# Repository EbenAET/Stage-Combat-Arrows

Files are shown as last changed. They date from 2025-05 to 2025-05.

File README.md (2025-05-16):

# Stage-Combat-Arrows
## A teaching tool for stage combat. These 3d printed arrows are large and easy to see. They point in the direction of the blade edge to help those training in stage combat to get used to blade orientation.

### Background: 
Professor Zev Steinrock at UIUC came to me requesting a simple solution to a visual tool he's incorporated when teaching his students the basics of stage combat with blades. Prof. Steinrock used hand cut cardboard arrows that would be skewered on the blades so the arrows would point towards the blade edge. Because of the time and material waste inherent in the creation of the cardboard arrows, he asked if I could come up with a simpler solution. Through basic iteration, I modeled a 3d printed arrow that contains a small rectangular window in the center and a screwdown clamp to keep a gripping medium in place. For the gripping medium, I've been using small rectangular cuts of neoprene yoga mats, though I am also trying out high friction rubber, and of course regular cardboard could be used as well. When the gripping medium wears out, it is easy to replace with another small rectangular piece. When using the neoprene and rubber, I recommend pre-punching screw holes to keep the material from jamming in the threads of the nuts.

### Included files:
- README | [README.md](https://github.com/EbenAET/Stage-Combat-Arrows/blob/b53a6de669d511d3e0b45057282f3c255a9eaaa4/README.md)
- Full drawings of model and assembly | [Combat Arrow v2.pdf](https://github.com/EbenAET/Stage-Combat-Arrows/blob/b33ad56709a9fc461572b4b7754411686f48d95c/Combat%20Arrow%20v2.pdf)
- Fusion360 Model | [Combat Arrow Assembly v9.f3z](https://github.com/EbenAET/Stage-Combat-Arrows/blob/0b1ade3ec6ca6f517fa18b048789da9054919ed2/3d-model/Combat%20Arrow%20Assembly%20v9.f3z)
- 3d Models for printing | [Arrow Body.3mf](https://github.com/EbenAET/Stage-Combat-Arrows/blob/0b1ade3ec6ca6f517fa18b048789da9054919ed2/3d-model/Arrow%20Body.3mf) and [Clamp.3mf](3d-model/Clamp.3mf)
- Prototype pictures | [Prototype image directory](images)
- Creative Commons License | [CC-A4](https://github.com/EbenAET/Stage-Combat-Arrows/blob/b53a6de669d511d3e0b45057282f3c255a9eaaa4/license)

### Materials needed (per unit made):
- 3x 6-32 Hex Nuts | [McMaster Carr Item 90480A007](https://www.mcmaster.com/90480A007/)
- 3x 6-32x1/4 Low Head SOC Cap Machine Screws | [McMaster Carr Item 93615A210](https://www.mcmaster.com/93615A210/)
- Super Glue
- Printer filament (I used PLA-CR)
- Finishing enamel (I used clear nail polish)
- Spray paint (if desired)
- Clear polycrylic (if paint is used)
- Gripping medium (I used neoprene rubber)

### 3d Printing Settings (PLA)
- Layer height - 0.08
- Ironing - All top surfaces
- Support - on (to help support hex sockets)

### Assembly
1. Print out both .3mf files
2. Glue 6-32 nuts into hex sockets - **be sure not to get glue in threads**
3. When glue is cured, apply enamel coat to 3d printed pieces
4. When enamel is cured, spray paint two even layers on all visable faces (if desired) | **I recommend setting screws into nuts for painting to keep paint from getting in the threads**
5. When paint is cured, lightly brush on one coat of clear polycrylic (if painted)
6. Cut a small rectangle of your gripping medium sized to fit in the arrow window frame
7. (Optional) pre-punch holes to make it easier to screw in machine screws
8. Compress gripping medium between arrow and clamp, install the 3 machine screws
9. Cut a small vertical slice in the center of the medium, smaller than the blade it will be used on
10. Skewer arrow on blade, pointing towards edge

### Alternate Assembly Notes
- Depending on thickness and grippyness of gripping medium, users may have to cut two small rectangles (slightly larger than half the width of the clamping size) and overlap in center.
- It is possible you may have to size up the machine screws if thickness of gripping medium is greater than what was used in the prototypes.

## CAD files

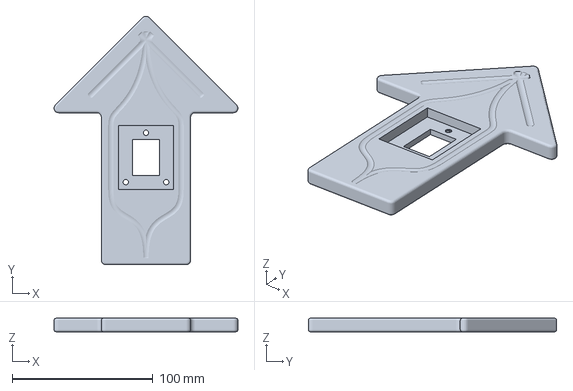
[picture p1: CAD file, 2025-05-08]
3d-model/Arrow Body.3mf
130.7 x 176.5 x 9.63 mm

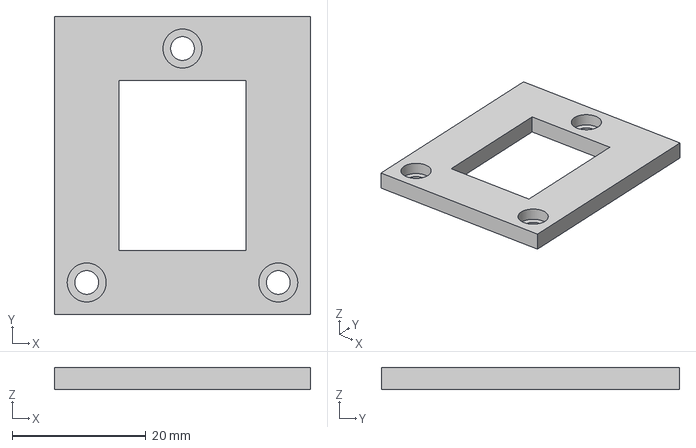
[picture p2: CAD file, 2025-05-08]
3d-model/Clamp.3mf
38.4 x 44.7 x 3.35 mm

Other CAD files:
3d-model/Combat Arrow Assembly v9.f3z

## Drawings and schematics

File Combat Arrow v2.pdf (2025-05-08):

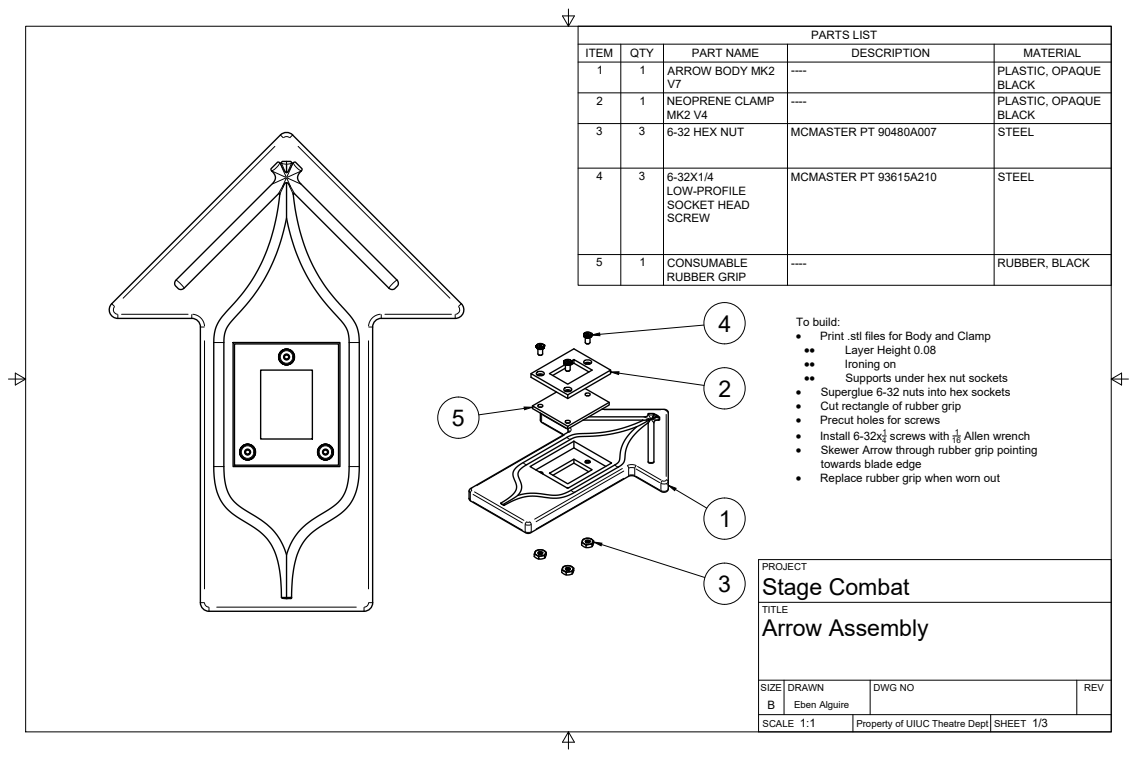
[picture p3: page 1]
Stage Combat; Arrow Assembly; PARTS LIST; To build:; Layer Height 0.08; Ironing on; Supports under hex nut sockets; screws with 1; Allen wrench

ITEM | QTY | PART NAME | DESCRIPTION | MATERIAL
1 | 1 | ARROW BODY MK2 V7 | ---- | PLASTIC, OPAQUE BLACK

2 | 1 | NEOPRENE CLAMP MK2 V4 | ---- | PLASTIC, OPAQUE BLACK

3 | 3 | 6-32 HEX NUT | MCMASTER PT 90480A007 | STEEL

4 | 3 | 6-32X1/4 LOW-PROFILE SOCKET HEAD SCREW | MCMASTER PT 93615A210 | STEEL

5 | 1 | CONSUMABLE RUBBER GRIP | ---- | RUBBER, BLACK

· Print .stl files for Body and Clamp
· Superglue 6-32 nuts into hex sockets
· Cut rectangle of rubber grip
· Precut holes for screws
· Install 6-32x1
· Skewer Arrow through rubber grip pointing
towards blade edge
· Replace rubber grip when worn out

SIZE B | DRAWN Eben Alguire | DWG NO | REV

1:1 SCALE | Property of UIUC Theatre Dept | 1/3 SHEET

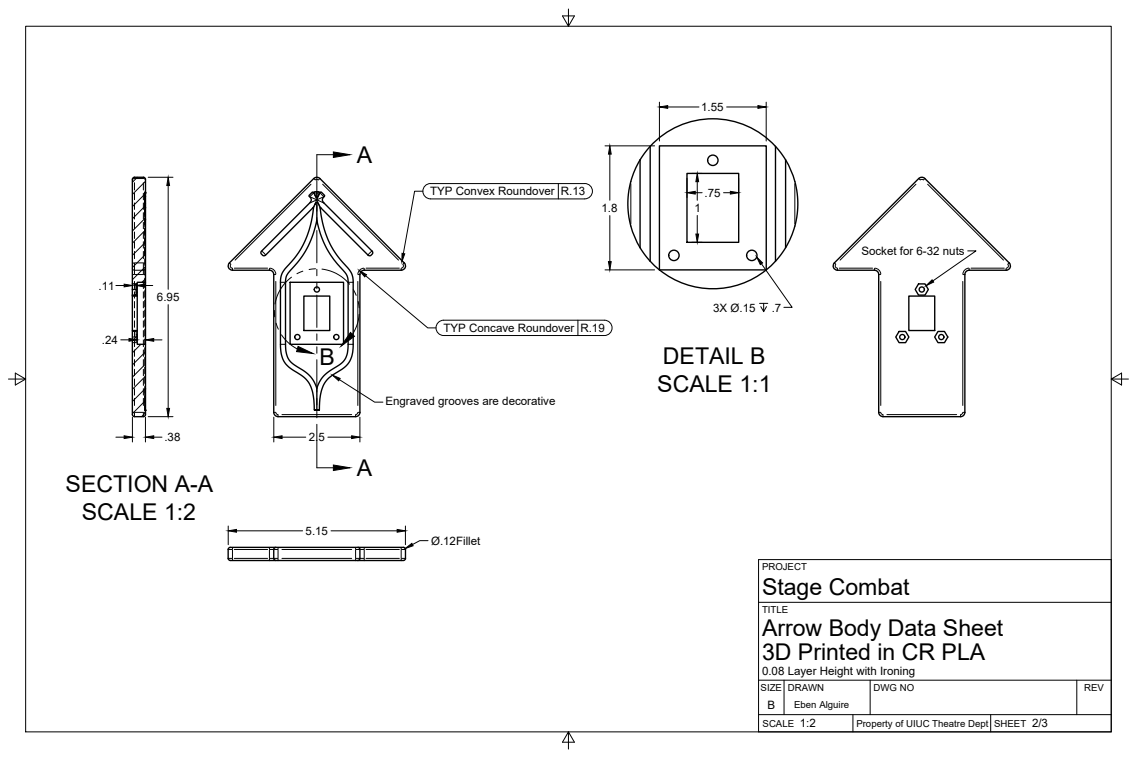
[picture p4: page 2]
SECTION A-A SCALE 1:2; TYP Convex Roundover; TYP Concave Roundover; DETAIL B; SCALE 1:1

Socket for 6-32 nuts

Engraved grooves are decorative

PROJECT
Stage Combat
Arrow Body Data Sheet
3D Printed in CR PLA

0.08 Layer Height with Ironing

SIZE | DRAWN | DWG NO | REV

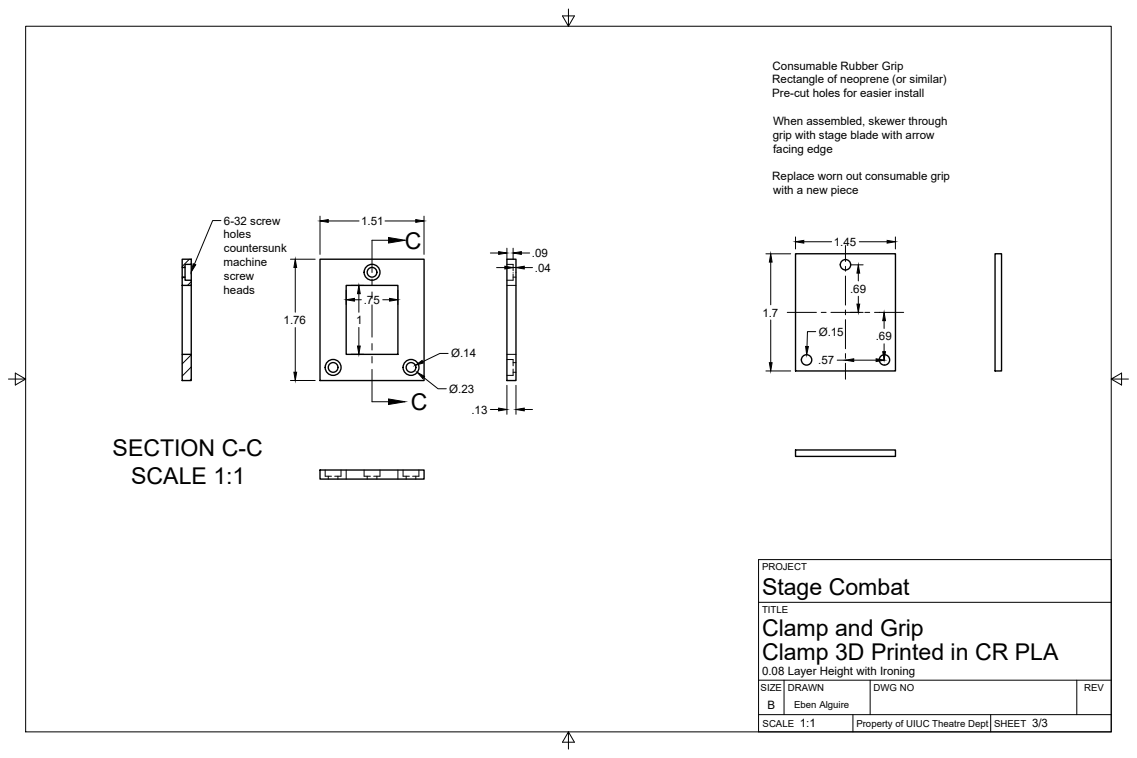
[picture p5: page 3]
SECTION C-C SCALE 1:1; 6-32 screw

Consumable Rubber Grip
Rectangle of neoprene (or similar)
Pre-cut holes for easier install

When assembled, skewer through
grip with stage blade with arrow
facing edge

Replace worn out consumable grip
with a new piece

PROJECT
Stage Combat
Clamp and Grip
Clamp 3D Printed in CR PLA

0.08 Layer Height with Ironing

SIZE | DRAWN | DWG NO | REV

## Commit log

2025-05-08 Initial file upload
    [Arrow Body.3mf, Clamp.3mf, Combat Arrow Assembly v9.f3z]
2025-05-16 Rename Arrow Prototype 1.jpg to images/Arrow Prototype 1.jpg
2025-05-16 Rename Arrow Prototype 2.jpg to images/Arrow Prototype 2.jpg
2025-05-16 Rename Arrow Body.3mf to 3d-model/Arrow Body.3mf
    [Arrow Body.3mf]
2025-05-16 Rename Combat Arrow Assembly v9.f3z to 3d-model/Combat Arrow Assembly v9.f3z
    [Combat Arrow Assembly v9.f3z]
